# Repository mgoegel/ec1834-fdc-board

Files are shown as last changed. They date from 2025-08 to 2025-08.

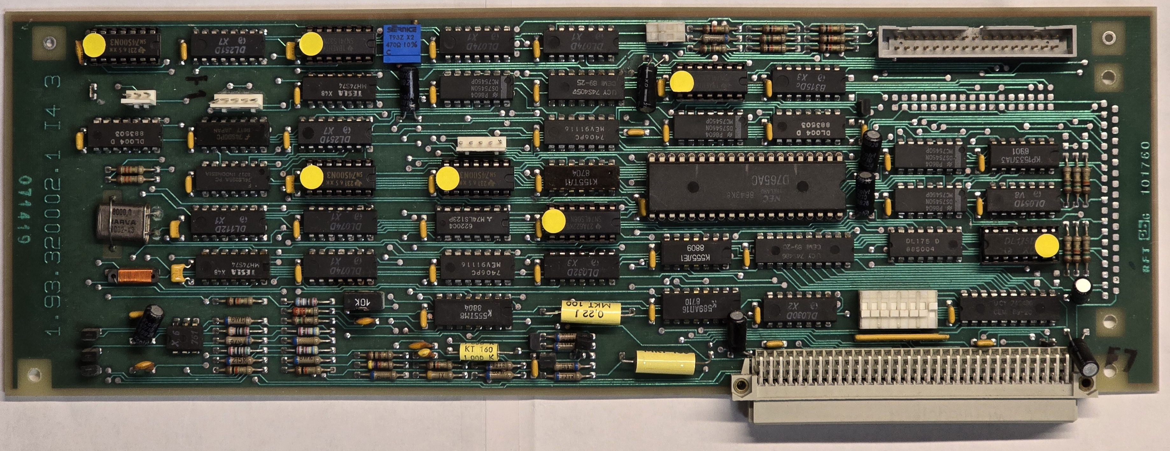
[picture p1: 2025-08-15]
images/20250804_173355 (2).jpg

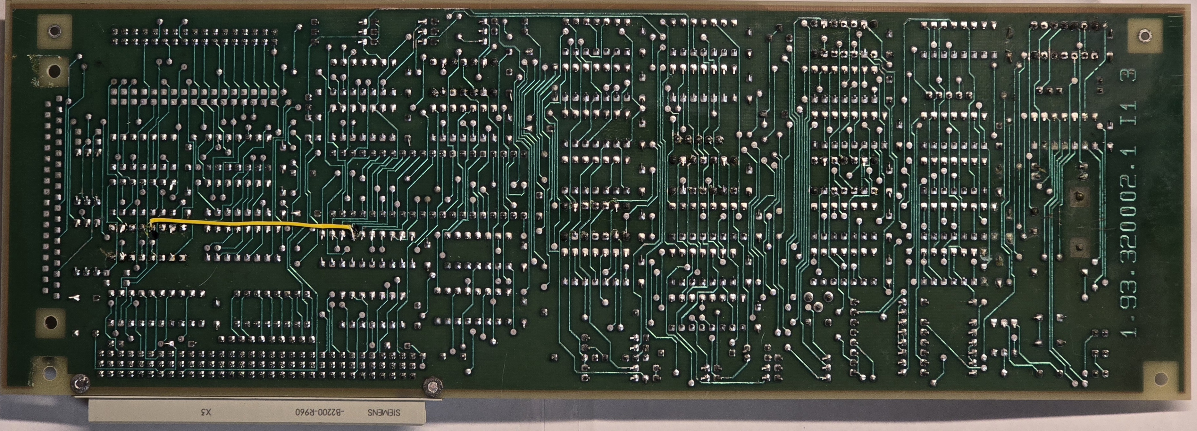
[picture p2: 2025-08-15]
images/20250804_173333 (2).jpg

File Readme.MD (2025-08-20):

# robotron EC1834 Floppy Disk Controller Schema

Der Robotron EC1834 ist ein 8086 basierter PC.

Hier ist die digitale Version des Schaltplans des Floppy Disk Controllers von 1988, inkl. Platinen-Layout.
Die Platine wurde aktuell noch nicht geroutet.

Falls sich das jemand antun möchte, halte ich ihn nicht davon ab... ;-)

https://www.robotrontechnik.de/index.htm?/html/computer/ec1834.htm
                       
## Anschlüsse
### DIP Switches

#### S1 Konfiguration
S1:1   - Abfrage /RDYL vom Laufwerk (1=EIN)
S1:2-7 - AUS
S1:8   - EIN bei U8272 D C04 (4 MHz Variante)
S1:8   - AUS bei U8272 D C08 (8 MHz Variante)
		 auch bei NEC D765A (8Mhz)

#### S2 Prüfschalter	 
ohne nähere Erläuterung
S2:1   - AUS
S2:2   - EIN

### Pin Header / Bus Connector

* X1 1 DIN41612 ISA SLOT
* X2 Anschluss externes Floppy
* X3 Floppy 1-2
* X4 Floppy 3-4
* X5 Prüfstecker 1
* X6 Prüfstecker 2
* X7 Prüfstecker 3

### Prüfstecker 

X5
    X5:1 - PLL Frequenz 2000kHz ± 2kHz (via R19)
    X5:2 - DATA WINDOW (mit X5:4)
    X5:3 - Unknown
    X5:4 - READ DATA (mit X5:2)
    X5:5 - N/V

                             ┌─┐                ┌─┐               ┌─┐        
     RDD X5:4          ──────┘ └────────────────┘ └───────────────┘ └─────── 
                                                                             
                          ┌────────┐        ┌────────┐         ┌────────┐    
                       ───┘        └────────┘        └─────────┘        └─── 
     DATA WINDOW                                                             
         X5:2          ───┐        ┌────────┐        ┌─────────┐        ┌────
                          ├────────┤        └────────┤         └────────┘    
                          │<------>│<--------------->│                       
                            1 us           2 us                              

X6
    X6:1 - CLK 8000kHz
    X6:2 - TA8 Disable (Signal auf GND)
    X6:3 - WRCLK
    
X7
    X7:1 - ?
    X7:2 - TA8
    X7:3 - /TA4
    X7:4 - TA3
    X7:5 - /TA2

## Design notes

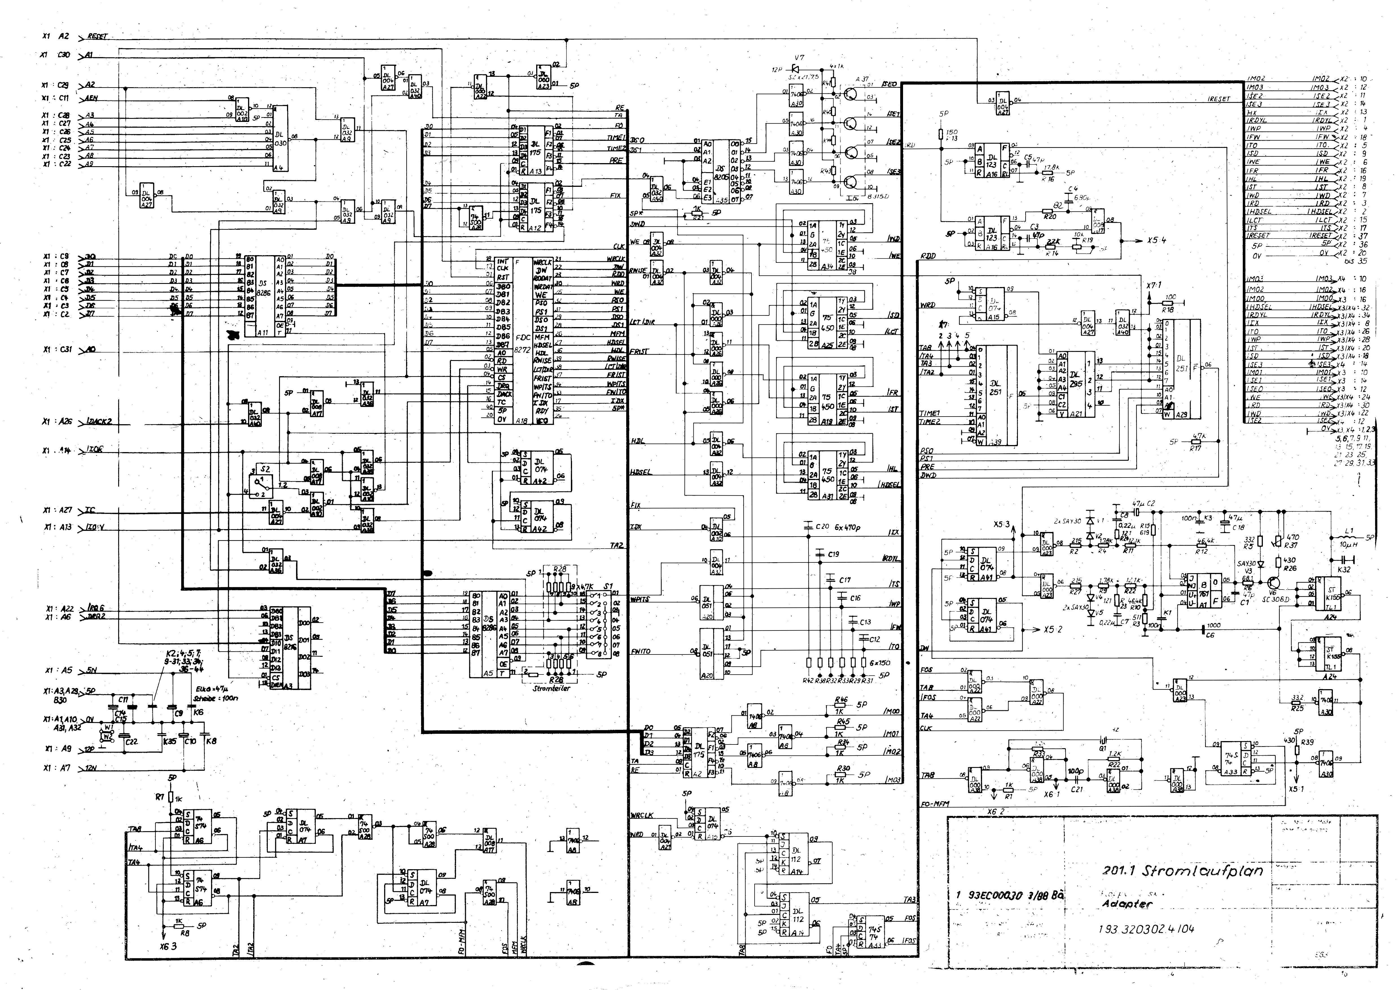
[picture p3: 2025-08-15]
images/FDC_1.93.320302.4-4.tiff

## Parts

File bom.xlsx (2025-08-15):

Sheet: IC
A1 | B761 |  | A30 | 7406
A2 | DL175 |  | A8 | 7406
A3 | DS8216 |  | A19 | 75450
A4 | DL030 |  | A25 | 75450
A5 | DS8286 |  | A31 | 75450
A6 | 74S74 |  | A34 | 75450
A7 | DL074 |  | A18 | 8272/uPD765
A8 | 7406 |  | A37 | B315
A9 | DL032 |  | A1 | B761
A10 | DL002 |  | A28 | DL000
A11 | DS8286 |  | A22 | DL000
A12 | DL175 |  | A23 | DL000
A13 | DL175 |  | A26 | DL000
A14 | DL112 |  | A38 | DL000
A15 | DL074 |  | A10 | DL002
A16 | DL123 |  | A27 | DL004
A17 | DL008 |  | A32 | DL004
A18 | 8272/uPD765 |  | A17 | DL008
A19 | 75450 |  | A4 | DL030
A20 | DL051 |  | A36 | DL032
A21 | DL295 |  | A40 | DL032
A22 | DL000 |  | A9 | DL032
A23 | DL000 |  | A20 | DL051
A24 | K155TL1 | SN7413 | A33 | DL074
A25 | 75450 |  | A6 | DL074
A26 | DL000 |  | A15 | DL074
A27 | DL004 |  | A41 | DL074
A28 | 74S00 |  | A42 | DL074
A29 | DL251 |  | A7 | DL074
A30 | 7406 |  | A14 | DL112
A31 | 75450 |  | A16 | DL123
A32 | DL004 |  | A12 | DL175
A33 | 74S74 |  | A13 | DL175
A34 | 75450 |  | A2 | DL175
A35 | DS8205 |  | A29 | DL251
A36 | DL032 |  | A39 | DL251
A37 | B315 |  | A21 | DL295
A38 | DL000 |  | A35 | DS8205
A39 | DL251 |  | A3 | DS8216
A40 | DL032 |  | A11 | DS8286
A41 | DL074 |  | A5 | DS8286
A42 | DL074 |  | A24 | K155TL1

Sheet: R
R1 | 1K |  | 12mm
R2 | 215
R3 | 511
R4 | 1,78K
R5 | 332
R6 | 68,1
R7 | 1K
R8 | 1K
R9 | 1,78K
R10 | 46,4K
R11 | 12,1K
R12 | 46,4K
R13 | 150
R14 | 22K
R15 | 619
R16 | 17,8K
R17 | 4,7K
R18 | 100
R19 | 10k Poti
R20 | 82
R21 | 1K
R22 | 12,1K | (R9/R23/R10)
R23 | 121
R24 | 121
R25 | 33,2
R26 | 430
R27 | 215
R28 | 9x4,7K BUS
R29 | 150
R30 | 1K
R31 | 150
R32 | 150
R33 | 150 | (A20/2)
R34 | 1K
R35 | 1,2K | (Q1/A38) R22
R36 | 1,2K | (A38/6-4) R33
R37 | 470 Poti
R38 | 150
R39 | 430
R40 | 1K
R41 | 1K
R42 | 150
R43 | 1K
R44 | 1K
R45 | 1K
R46 | 1K

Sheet: C
C1 | 47p
C2 | 47µ | Elko
C3 | 47p
C4 | 680p
C5 | 47p
C6 | 0,1µ | Folie | Axial
C7 | 0,22µ | Folie | Axial
C8 | 0,22µ | Folie | Axial
C9 | 47µ | Elko
C10 | 47µ | Elko
C11 | 47µ | Elko
C12 | 470p
C13 | 470p
C14 | 47µ | Elko
C15 | 47µ | Elko
C16 | 470p
C17 | 470p
C18 | 47µ | Elko
C19 | 470p
C20 | 470p
C21 | 100p
C22 | 47µ | Elko

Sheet: sonstige
V1 | SAY30
V2 | SAY30
V3 | SAY30
V4 | SAY30
V5 | SAY30
V6 | SC308D
V7 | SZx21/7,5
Q1 | 8000 kHz
L1 | 10µH
X1 | DIN41612-96 | EC1834BUS
X2 | IDC34 90° extern
X3 | IDC34
X4 | IDC34
X5 | Pin Header 1x5
X6 | Pin Header 1x3
X7 | Pin Header 1x5
S1 | DIP-SW8
S2 | DIP-SW2

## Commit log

2025-08-15 Bugfix in schematics documented
    [EC1834_FDC.kicad_sch]
2025-08-20 Schematics improved Added descriptions Fixed last missing PCB components
    [EC1834_FDC.kicad_sch, Power.kicad_sch]
2025-08-21 Removed old files mainboard files
    [EC1834-FDC.csv]
